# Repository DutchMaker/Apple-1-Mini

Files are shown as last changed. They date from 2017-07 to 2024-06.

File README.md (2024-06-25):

# Apple 1 Mini

*This build is currently in progress*

This project is a minified replica of the [**Apple 1**](https://en.wikipedia.org/wiki/Apple_I).  
It's built around a 6502 CPU, 6821 PIA (Peripheral Interface Adapter), RAM and ROM - just like the original Apple 1, but it uses an Arduino Nano to enable serial communication between the Apple 1 board and an external computer that acts as terminal.  
That means you can't hook up a keyboard and monitor directly to the board (yet!).  

The project is heavily inspired by the [*Briel Computers Apple 1 Replica*](http://www.brielcomputers.com/wordpress/?cat=17) and [*The Ben Heck Show*](https://github.com/thebenheckshow/158-tbhs-apple-1-replica)!

**What I have done:**
- [Redesigned the circuit](https://github.com/DutchMaker/Apple-1-Mini/blob/master/design/DesignSpark/revision1/schematic%20-%20Schematic.pdf) so I would fully understand every aspect of it.
- Designed a PCB that can be easily produced and included in a **modular DIY kit** for anyone that wants to build this at home.
- Programmed the ROM so it only contains BASIC, Krusader (assembler) and the Woz Monitor (memory monitor).
- Written firmware for the Arduino to enable serial communication in a way that gives the real *Apple 1 feeling*.
- Written a simple utility to upload data to the computer. This proved to be difficult with existing tools as there need to be specific delays in sending the data.

**What I have planned:**
- Design an expansion board that allows you to connect a keyboard an monitor directly to the board and run the Apple 1 standalone. The main PCB has an expansion header that allows an expansion board to be put on top of it (like a breakout board).
- Design a modular casing with laser cut parts. The casing will house the main board, but additional layers can be put on top of it to increase its size and allow for expansion boards to be added later on.
- Release several varations of a DIY kit for this project (PCB only, PCB + passives, PCB + passives + casing, complete kit, etc.) so others can easily build the computer at home.

**UPDATE (June 2024): Printer & SD storage support**  
[Simon Boak](https://github.com/simonboak/SB-A1) has added printer and SD storage support to the firmware.  
Read all about it in his detailed blog post: https://unimplementedtrap.com/apple-1-with-printer-sd-storage  
Thank you for this excellent contribution, Simon!

**Pictures of revision 1:**  

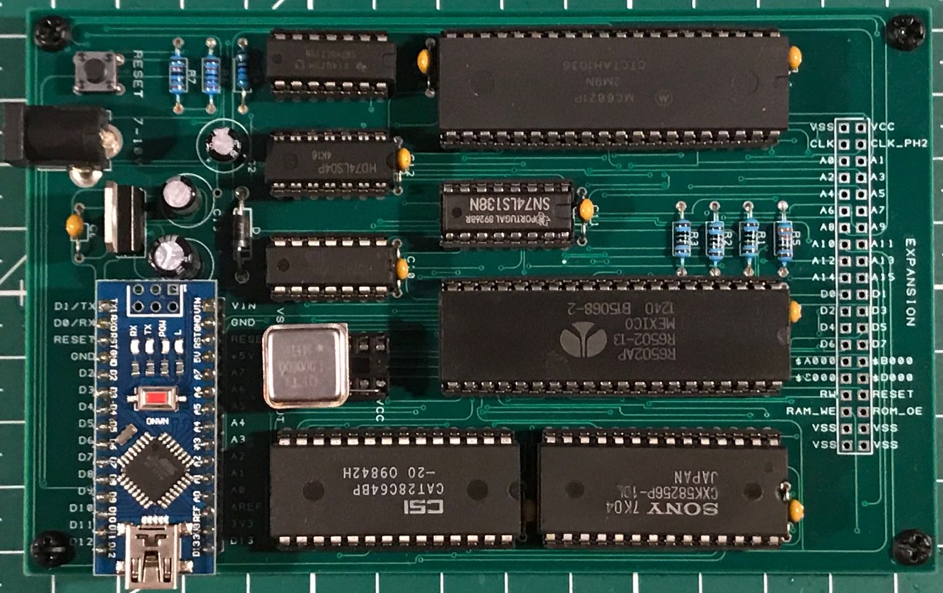
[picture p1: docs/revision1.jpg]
  
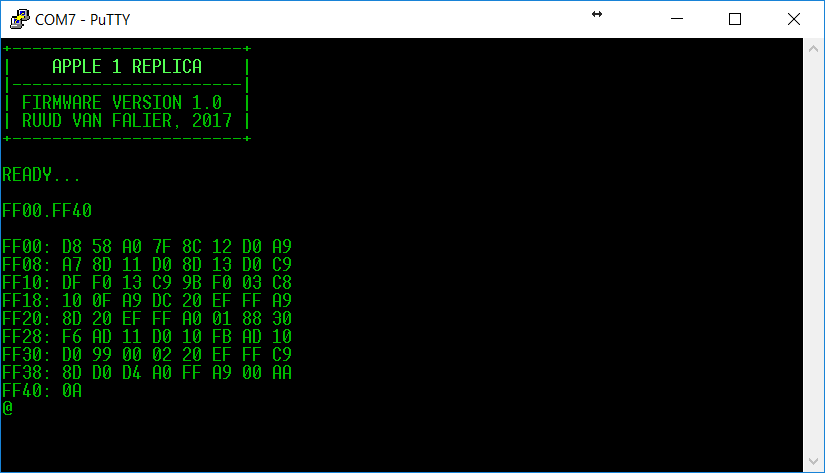
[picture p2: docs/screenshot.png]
  
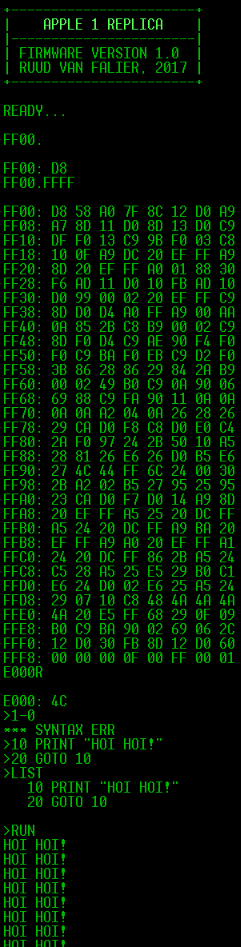
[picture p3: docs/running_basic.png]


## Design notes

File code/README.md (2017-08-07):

# Code folders

## Firmware
Contains Arduino code for the Apple 1 Mini firmware.

## Memory
Memory dump for the ROM.

## Programs
Program code for Apple 1 programs.

## Utilities
Utilities you may want to use with your Apple 1 Mini.

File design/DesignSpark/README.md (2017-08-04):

# Schematic & PCB design

You need to download [DesignSpark PCB 8](https://www.rs-online.com/designspark/pcb-software) to view & edit the schematic and PCB. 
Add the components folder to your component library first!  
 
The schematic is also [available as PDF](https://github.com/DutchMaker/Apple-1-Replica/blob/master/design/DesignSpark/revision1/schematic%20-%20Schematic.pdf).

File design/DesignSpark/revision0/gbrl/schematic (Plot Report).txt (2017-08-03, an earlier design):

Plot Report
-----------

Report Written:     Thursday, July 20, 2017
Design Path:        E:\Personal\Projects\Apple-1-Replica\design\DesignSpark\schematic.pcb
Design Title:       
Created:            20-7-2017 11:04:34
Last Saved:         20-7-2017 21:08:31
Editing Time:       603 min
Units:              mm (precision 1)

Device Settings
===============

Gerber Settings
===============

    Leading zero suppression.
    G01 assumed throughout.
    Line termination <*> <CR> <LF>.
    3.5 format absolute inches.

    Format commands defined in Gerber file.
    Aperture table defined in Gerber file.
    Hardware arcs allowed.

Drill Settings
==============

    Excellon Format 1    Format 3.5 absolute in inches.
    No zero suppression.

Plots Output
============

    Plot Job: "E:\Personal\Projects\Apple-1-Replica\design\DesignSpark\schematic.mop"

Gerber Output
=============

E:\Personal\Projects\Apple-1-Replica\design\DesignSpark\schematic - Top Silkscreen.gbr

    Layers:
    ------------------
    Top Silkscreen
    Board Outlines

    D-Code Shape  (thou)
    -----------------------
    D10    Round 19.69
    D11    Round 7.87
    D12    Round 5.00
    D13    Round 6.00
    D14    Round 3.00
    D15    Round 10.00
    D16    Round 16.00
    D17    Round 12.00

Gerber Output
=============

E:\Personal\Projects\Apple-1-Replica\design\DesignSpark\schematic - Top Copper.gbr

    Layers:
    --------------
    Top Copper

    D-Code Shape  (thou)
    ------------------------------------------
    D12    Round 5.00
    D15    Round 10.00
    D18    Round 196.85
    D19    Oval 60.00 X 110.00  Rotation 90
    D70    Round 60.00
    D71    Square 60.00
    D20    Oval 60.00 X 110.00
    D21    Round 70.00
    D22    Round 86.00
    D23    Round 56.00
    D24    Round 20.00
    D25    Round 32.00

Gerber Output
=============

E:\Personal\Projects\Apple-1-Replica\design\DesignSpark\schematic - Top Copper (Resist).gbr

    Layers:
    --------------
    Top Copper

    D-Code Shape  (thou)
    ------------------------------------------
    D26    Round 206.85
    D27    Oval 70.00 X 120.00  Rotation 90
    D28    Round 70.00
    D29    Square 70.00
    D72    Oval 70.00 X 120.00
    D73    Round 80.00
    D74    Round 96.00

Gerber Output
=============

E:\Personal\Projects\Apple-1-Replica\design\DesignSpark\schematic - Bottom Copper.gbr

    Layers:
    -----------------
    Bottom Copper

    D-Code Shape  (thou)
    ------------------------------------------
    D12    Round 5.00
    D15    Round 10.00
    D18    Round 196.85
    D19    Oval 60.00 X 110.00  Rotation 90
    D70    Round 60.00
    D71    Square 60.00
    D21    Round 70.00
    D22    Round 86.00
    D23    Round 56.00
    D24    Round 20.00
    D25    Round 32.00
    D75    Oval 60.00 X 110.00

Gerber Output
=============

E:\Personal\Projects\Apple-1-Replica\design\DesignSpark\schematic - Bottom Copper (Resist).gbr

    Layers:
    -----------------
    Bottom Copper

    D-Code Shape  (thou)
    ------------------------------------------
    D26    Round 206.85
    D27    Oval 70.00 X 120.00  Rotation 90
    D28    Round 70.00
    D29    Square 70.00
    D72    Oval 70.00 X 120.00
    D73    Round 80.00
    D74    Round 96.00

NC Drill Output
===============

E:\Personal\Projects\Apple-1-Replica\design\DesignSpark\schematic - Drill Data - [Through Hole].drl

    Output:
    ---------------------------
    Plated Round Drill Holes
    Plated Slots
    Plated Board Outlines

    Tool  Size         Count   ID
    ------------------------------------
    T001  000.01600 in 363
    T002  000.03200 in 272
    T003  000.03500 in 72
    T004  000.03937 in 4
    T005  000.04200 in 3
    T006  000.06200 in 2
    T007  000.11811 in 4
    ------------------------------------
    Total              720
    ------------------------------------

E:\Personal\Projects\Apple-1-Replica\design\DesignSpark\schematic - Drill Data - [Through Hole] (Unplated).drl

    Output:
    -----------------------------
    Unplated Round Drill Holes
    Unplated Slots
    Unplated Board Outlines

    Tool  Size         Count   ID
    ------------------------------------
    T001  000.02500 in 1
    ------------------------------------
    Total              1
    ------------------------------------

Gerber Output
=============

E:\Personal\Projects\Apple-1-Replica\design\DesignSpark\schematic - Drill Ident Drawing - [Through Hole].gbr

    Layers:
    ------------------
    [Through Hole]

Drill Ident Drawing
===================

    Drill Plated Size Shape ID
    -----------------------------------
    118   Y      100  Round A
    32    Y      100  Round B
    35    Y      100  Round C
    39    Y      100  Round D
    42    Y      100  Round E
    62    Y      100  Round F
    16    Y      100  Round G

    D-Code Shape  (thou)
    -----------------------
    D12    Round 5.00
    D76    Round 100.00

End Of Report.

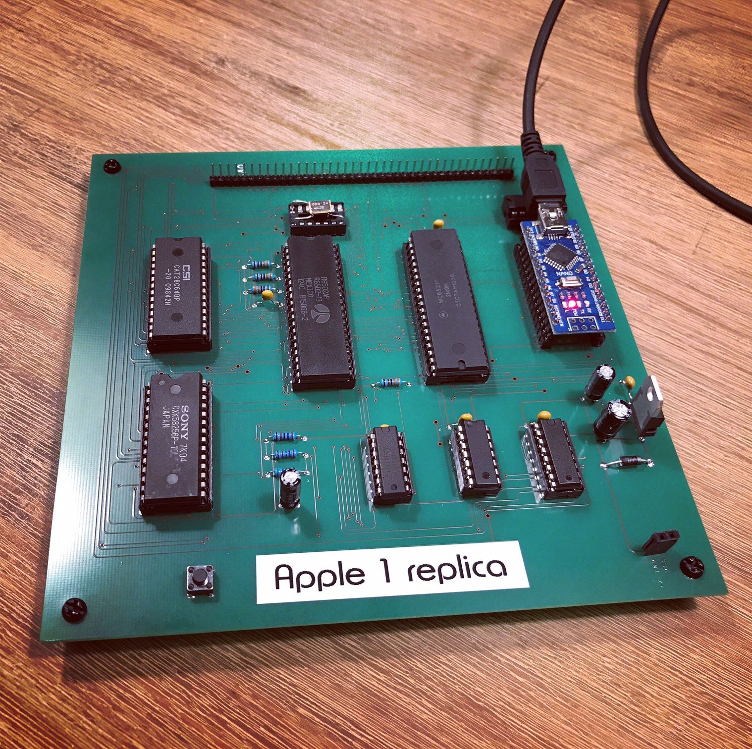
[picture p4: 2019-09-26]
docs/revision0.jpg

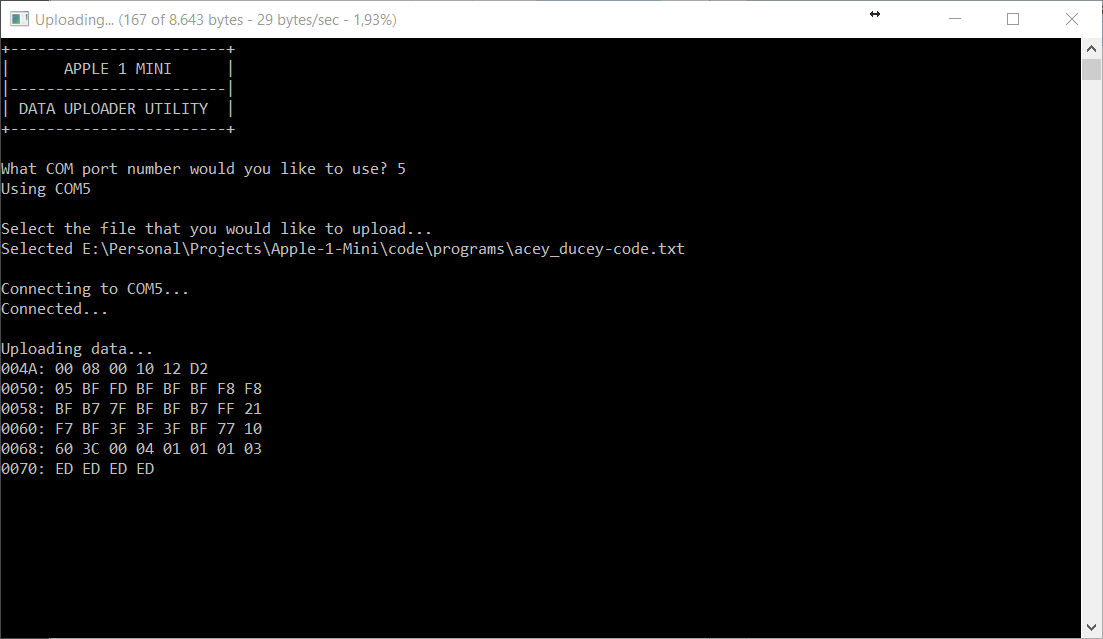
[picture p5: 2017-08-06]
docs/data-uploader.png

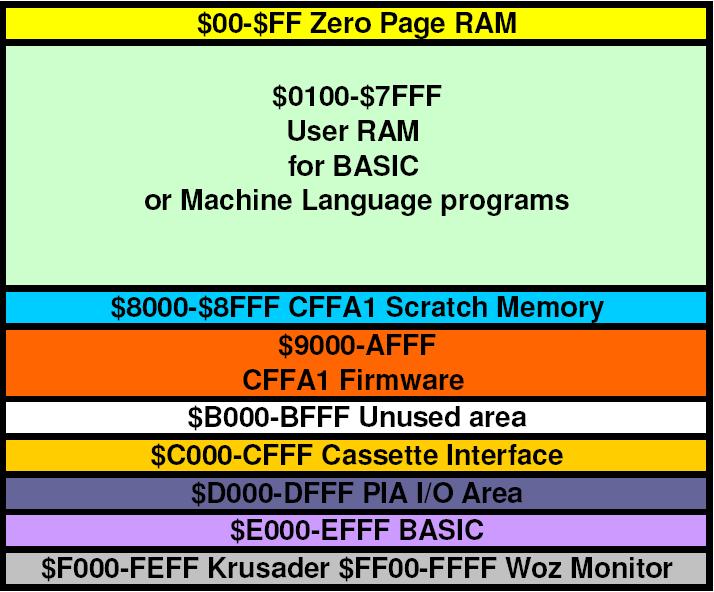
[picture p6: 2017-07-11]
code/memory/memory-map.jpg

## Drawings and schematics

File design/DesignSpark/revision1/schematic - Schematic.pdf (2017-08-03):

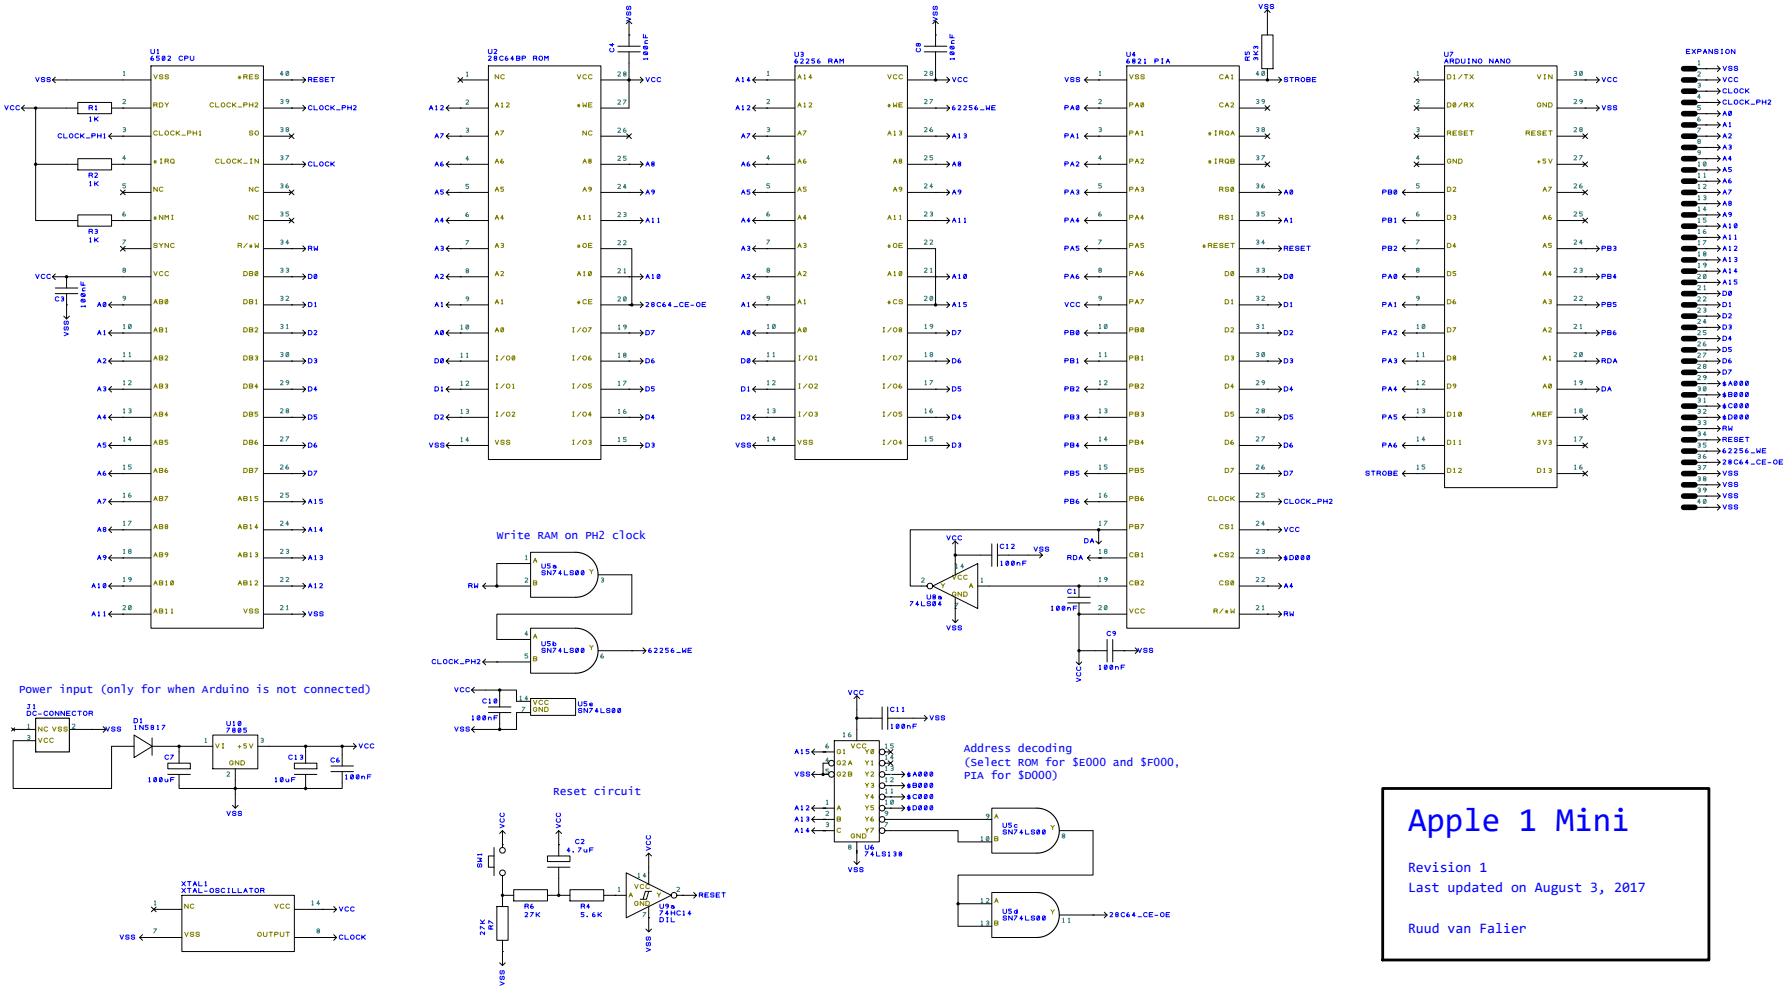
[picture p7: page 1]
Apple 1 Mini; Reset circuit

Write RAM on PH2 clock

Power input (only for when Arduino is not connected)

Address decoding
(Select ROM for $E000 and $F000,
PIA for $D000)

Revision 1
Last updated on August 3, 2017

Ruud van Falier

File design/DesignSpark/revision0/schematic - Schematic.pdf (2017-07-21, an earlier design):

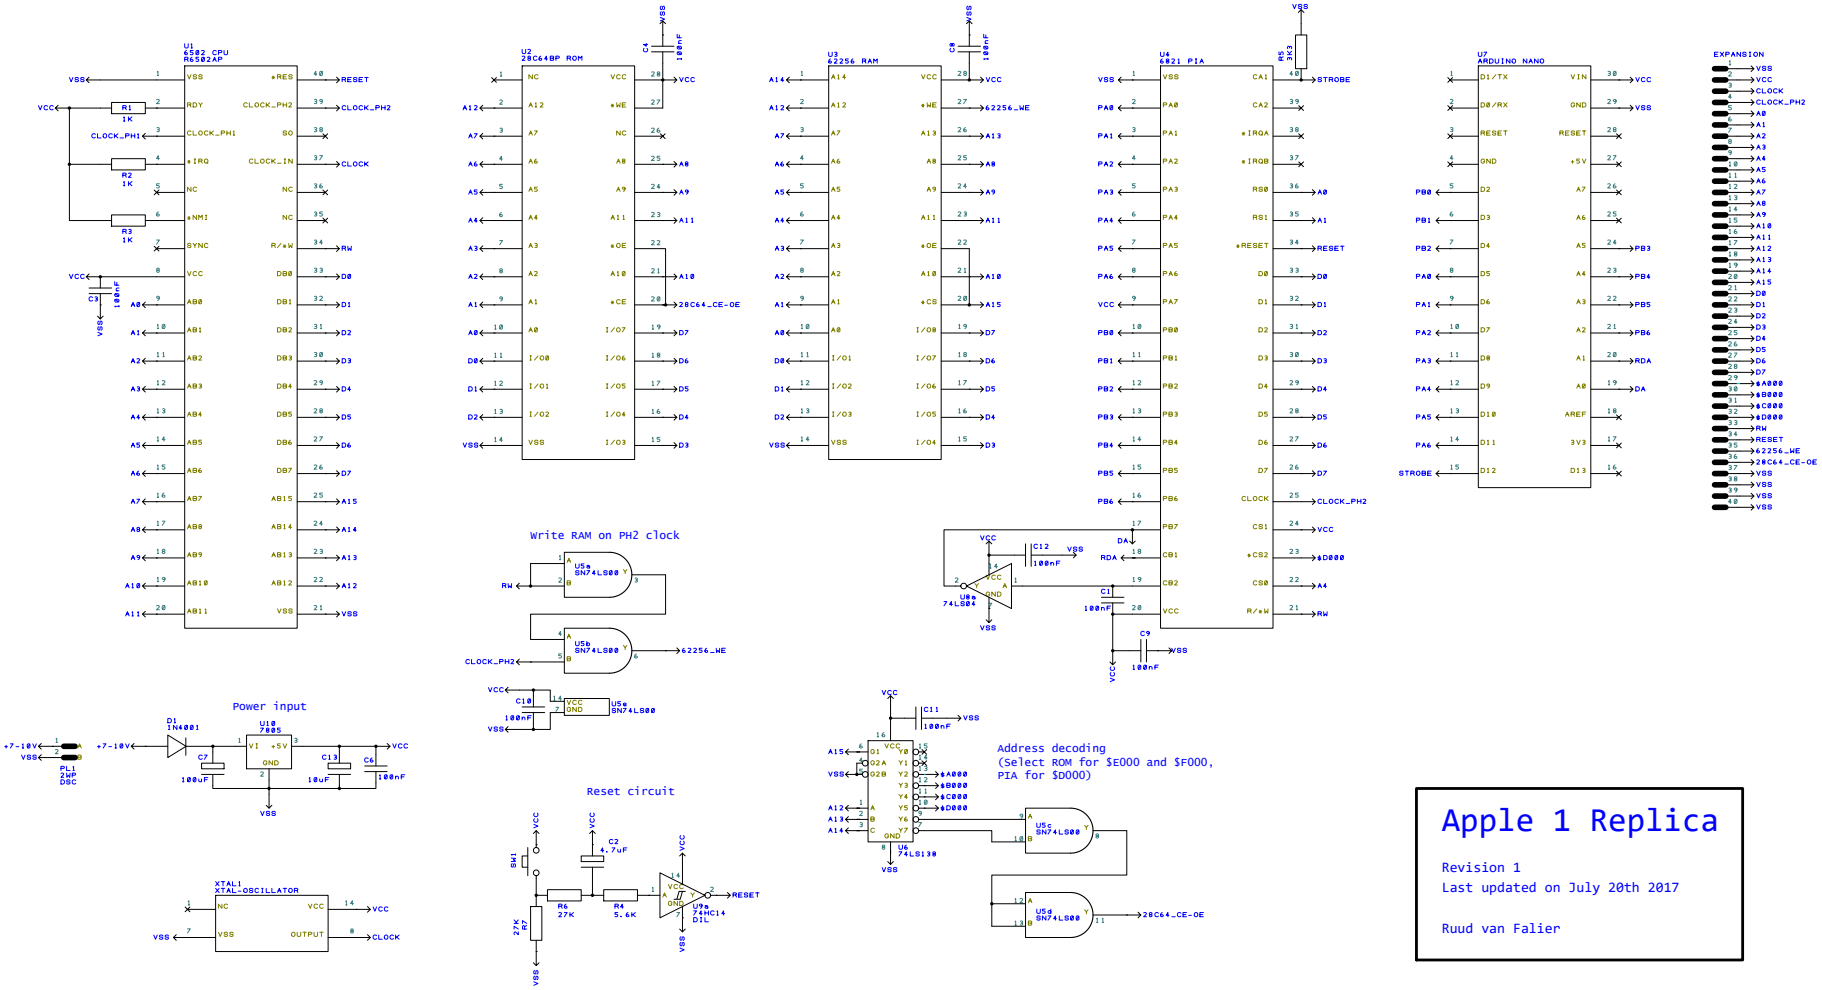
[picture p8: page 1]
Apple 1 Replica; Power input; Reset circuit

Write RAM on PH2 clock

Address decoding
(Select ROM for $E000 and $F000,
PIA for $D000)

Revision 1
Last updated on July 20th 2017

Ruud van Falier

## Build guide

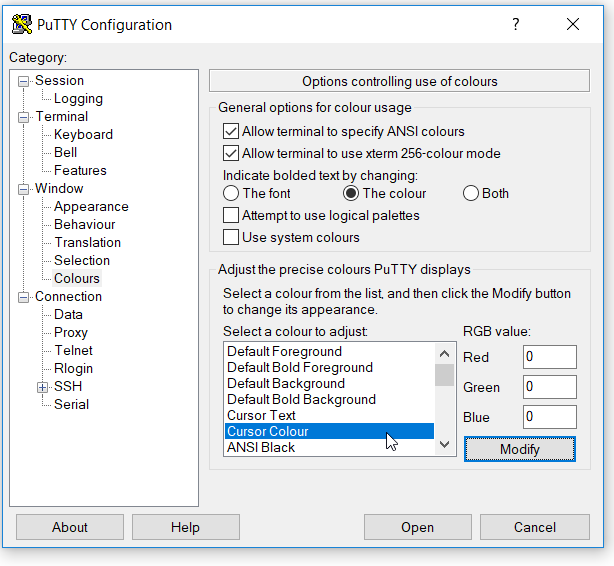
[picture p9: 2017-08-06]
docs/PuTTY-setup/PuTTY settings colours cursor.png

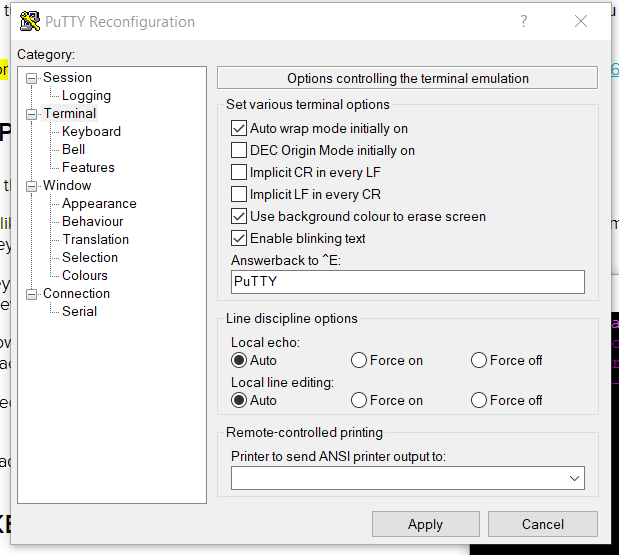
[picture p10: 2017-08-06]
docs/PuTTY-setup/PuTTY settings.png

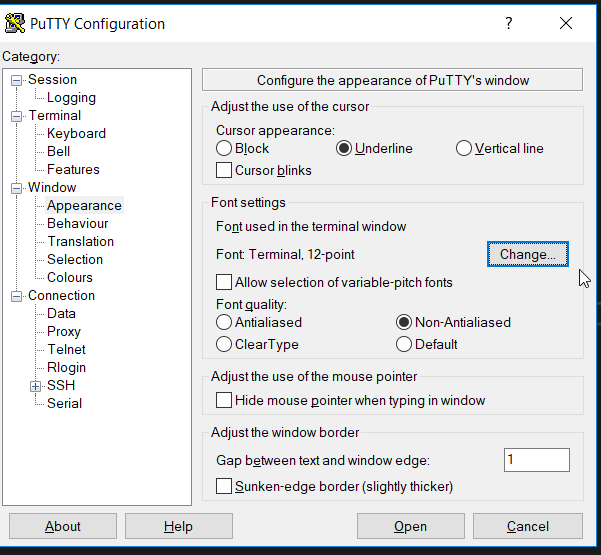
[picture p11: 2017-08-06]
docs/PuTTY-setup/PuTTY settings font.png

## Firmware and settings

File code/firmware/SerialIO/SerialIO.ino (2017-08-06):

// ---------------------------------------------------------------------------------- //
// Apple 1 Mini firmware for Arduino                                                  //
//                                                                                    //
// Version 1.0                                                                        //
// By Ruud van Falier                                                                 //
//                                                                                    //
// Enables serial communication between an Arduino and the Apple 1 PIA.               //
// Also implements a blinking cursor and green text using VT100 escape codes          //
// (VT100 codes only tested with PuTTY client!)                                       //
//                                                                                    //
// Heavily based on Propeller source code from Briel Computers' Apple 1 replica.      //
// ---------------------------------------------------------------------------------- //

// Port definitions (Arduino pins connected to the PIA)
#define PIN_DA  A0
#define PIN_RDA A1
#define PIN_PB0 2
#define PIN_PB1 3
#define PIN_PB2 4
#define PIN_PB3 A5
#define PIN_PB4 A4
#define PIN_PB5 A3
#define PIN_PB6 A2
#define PIN_PA0 5
#define PIN_PA1 6
#define PIN_PA2 7
#define PIN_PA3 8
#define PIN_PA4 9
#define PIN_PA5 10
#define PIN_PA6 11
#define PIN_STROBE 12

#define DELAY_VIDEO 1
#define DELAY_ASCII 1

// VT100 codes (used for cursor and text color implementation)
#define VT100_OFF           "\033[0m"     // Disable formatting
#define VT100_DEFAULT       "\033[32m"    // Color green
#define VT100_BLINK         "\033[5;32m"  // Blink color green
#define VT100_BOLD          "\033[1;32m"  // Bold color green
#define VT100_CLS           "\033[2J"     // Clear screen
#define VT100_RESET_CURSOR  "\033[H"      // Position cursor in top left corner
#define VT100_CURSOR_LEFT   "\033[1D"     // Move cursor one column to the left
#define VT100_ERASE_EOL     "\033[K"      // Erase from cursor until end of line
#define CURSOR_CHAR   "@"

// Global variables
uint8_t video_data = 0;
uint8_t video_data_pins[] = { PIN_PB0, PIN_PB1, PIN_PB2, PIN_PB3, PIN_PB4, PIN_PB5, PIN_PB6 };
uint8_t serial_data;

bool cursor_visible = false;

/*
 * Program initialization
 */
void setup() 
{
  // Setup video data pins (output from the PIA)
  pinMode(PIN_RDA, OUTPUT);
  pinMode(PIN_DA, INPUT);
  pinMode(PIN_PB0, INPUT);
  pinMode(PIN_PB1, INPUT);
  pinMode(PIN_PB2, INPUT);
  pinMode(PIN_PB3, INPUT);
  pinMode(PIN_PB4, INPUT);
  pinMode(PIN_PB5, INPUT);
  pinMode(PIN_PB6, INPUT);

  // Setup ASCII data pins (input for the PIA)
  pinMode(PIN_STROBE, OUTPUT);
  pinMode(PIN_PA0, OUTPUT);
  pinMode(PIN_PA1, OUTPUT);
  pinMode(PIN_PA2, OUTPUT);
  pinMode(PIN_PA3, OUTPUT);
  pinMode(PIN_PA4, OUTPUT);
  pinMode(PIN_PA5, OUTPUT);
  pinMode(PIN_PA6, OUTPUT);

  Serial.begin(9600);
 
  display_boot_message();
}

/*
 * Program loop
 */
void loop() 
{
  process_video_data();
  process_serial_data(); 
}

/*
 * Displays the Apple 1 Replica firmware boot message and enables the blinking cursor
 */
void display_boot_message()
{
  cursor_visible = false;

  Serial.print(VT100_CLS);
  Serial.print(VT100_RESET_CURSOR);
  Serial.print(VT100_OFF);
  Serial.print(VT100_DEFAULT);
  Serial.println("+------------------------+");
  Serial.print("|      ");
  Serial.print(VT100_OFF);
  Serial.print(VT100_BOLD);
  Serial.print("APPLE 1 MINI");
  Serial.print(VT100_OFF);
  Serial.print(VT100_DEFAULT);
  Serial.println("      |");
  Serial.print(VT100_OFF);
  Serial.print(VT100_DEFAULT);
  Serial.println("|------------------------|");
  Serial.println("| FIRMWARE VERSION 1.0   |");
  Serial.println("| RUUD VAN FALIER, 2017  |");
  Serial.println("+------------------------+");
  Serial.println();
  Serial.println("READY...");
  Serial.println();
  Serial.print(VT100_OFF);

  show_cursor();
}

/*
 * Retrieves video (character) data from the PIA and sends it to the user over the serial connection.
 */
void process_video_data()
{
  // Tell the PIA we are ready to receive data.
  digitalWrite(PIN_RDA, HIGH);
  delay(DELAY_VIDEO);

  while (digitalRead(PIN_DA))
  {
    // Data is available.
    video_data = 0;

    // Decode the data bits to a byte.
    for (int i = 0; i < 7; i++)
    { 
      if (digitalRead(video_data_pins[i]))
      {
        video_data |= (1 << i);
      }
    }

    // Send video data over serial connection.
    if (video_data == 13)
    {
      // Carrage return.
      hide_cursor();
      Serial.println();
    }
    else if (video_data > 31)
    {
      // Display-compatible character.
      hide_cursor();
      Serial.print(VT100_DEFAULT);
      Serial.print((char)video_data);
      Serial.print(VT100_OFF);
    }

    // Done receiving this byte.
    digitalWrite(PIN_RDA, LOW);
    delay(DELAY_VIDEO);

    // Tell the PIA we are ready to receive more data.
    digitalWrite(PIN_RDA, HIGH);
    delay(DELAY_VIDEO);
  }

  show_cursor();
}

/*
 * Processes data received from the serial connection.
 * Puts the received data on to the PIA where the CPU will read it from.
 */
void process_serial_data()
{
  // Wait for serial data coming in.
  while (Serial.available() > 0)
  {
    serial_data = Serial.read();

    if (serial_data == 203) 
    {
      // Translate uppercase ESC to normal ESC.
      serial_data = 27;
    }

    if (serial_data >= 97 && serial_data <= 122)
    {
      // Translate lowercase characters to uppercase as the Apple 1 only supports uppercase.
      serial_data -= 32;
    }

    if (serial_data < 96)   
    {
      // Encode any Apple 1 compatible character to data bits.
      digitalWrite(PIN_PA6, bitRead(serial_data, 6));
      digitalWrite(PIN_PA5, bitRead(serial_data, 5));
      digitalWrite(PIN_PA4, bitRead(serial_data, 4));
      digitalWrite(PIN_PA3, bitRead(serial_data, 3));
      digitalWrite(PIN_PA2, bitRead(serial_data, 2));
      digitalWrite(PIN_PA1, bitRead(serial_data, 1));
      digitalWrite(PIN_PA0, bitRead(serial_data, 0));

      // Pulse the STROBE bit so the PIA will process the input.
      digitalWrite(PIN_STROBE, HIGH);
      delay(DELAY_ASCII);
      digitalWrite(PIN_STROBE, LOW);
    }

    process_video_data();
  }
}

/*
 * Remove the cursor character from the screen by sending a backspace.
 */
void hide_cursor()
{
  if (cursor_visible)
  {
    Serial.print(VT100_CURSOR_LEFT);
    Serial.print(VT100_ERASE_EOL);
    cursor_visible = false;
  }
}

/*
 * Display blinking cursor character.
 */
void show_cursor()
{
  if (!cursor_visible)
  {
    Serial.print(VT100_BLINK);
    Serial.print(CURSOR_CHAR);
    Serial.print(VT100_OFF);
    cursor_visible = true;
  }
}

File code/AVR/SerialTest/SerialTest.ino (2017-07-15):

#define DA  A0
#define RDA A1
#define PB0 2
#define PB1 3
#define PB2 4
#define PB3 A5
#define PB4 A4
#define PB5 A3
#define PB6 A2
#define PA0 5
#define PA1 6
#define PA2 7
#define PA3 8
#define PA4 9
#define PA5 10
#define PA6 11
#define STROBE 12

uint8_t video_data = 0;
uint8_t video_data_pins[] = { PB0, PB1, PB2, PB3, PB4, PB5, PB6 };
uint8_t serial_data;

void setup() 
{
  // Video data pins
  pinMode(RDA, OUTPUT);
  pinMode(DA, INPUT);
  pinMode(PB0, INPUT);
  pinMode(PB1, INPUT);
  pinMode(PB2, INPUT);
  pinMode(PB3, INPUT);
  pinMode(PB4, INPUT);
  pinMode(PB5, INPUT);
  pinMode(PB6, INPUT);

  // ASCII data pins
  pinMode(STROBE, OUTPUT);
  pinMode(PA0, OUTPUT);
  pinMode(PA1, OUTPUT);
  pinMode(PA2, OUTPUT);
  pinMode(PA3, OUTPUT);
  pinMode(PA4, OUTPUT);
  pinMode(PA5, OUTPUT);
  pinMode(PA6, OUTPUT);

  Serial.begin(9600);
  Serial.println("Arduino ready...");
}

void loop() 
{
  process_video_data();
  process_serial_data();  
}

void process_video_data()
{
  digitalWrite(RDA, HIGH);
  delayMicroseconds(20);

  if (digitalRead(DA))
  {
    video_data = 0;

    for (int i = 0; i < 7; i++)
    { 
      if (digitalRead(video_data_pins[i]))
      {
        video_data |= (1 << i);
      }
    }

    if (video_data == 13)
    {
      Serial.println();
    }
    else if (video_data > 31)
    {
      Serial.print((char)video_data);
    }

    digitalWrite(RDA, LOW);
    delayMicroseconds(20);
  }
}

void process_serial_data()
{
  if (Serial.available() > 0) 
  {
    serial_data = Serial.read();

    if (serial_data == 203) // Uppercase ESC
    {
      serial_data = 27;
    }

    if (serial_data >= 97 && serial_data <= 122)  // lower case a-z
    {
      serial_data -= 32;
    }

    if (serial_data < 96)   // Is the character Apple 1 compatible?
    {      
      digitalWrite(PA6, bitRead(serial_data, 6));
      digitalWrite(PA5, bitRead(serial_data, 5));
      digitalWrite(PA4, bitRead(serial_data, 4));
      digitalWrite(PA3, bitRead(serial_data, 3));
      digitalWrite(PA2, bitRead(serial_data, 2));
      digitalWrite(PA1, bitRead(serial_data, 1));
      digitalWrite(PA0, bitRead(serial_data, 0));

      digitalWrite(STROBE, HIGH);
      delayMicroseconds(20);
      digitalWrite(STROBE, LOW);
    }

    /*
    if (serial_data == 13)
    {
      Serial.println();
    }
    else
    {
      Serial.print((char)serial_data);
    }
    */
  }
}

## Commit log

2017-07-11 Added ROM image
    [schematic.sch]
2017-07-13 Schematic for PIA updated
    [schematic.sch]
2017-07-14 Added code for apple 1 programs and started AVR code for IO
    [schematic.sch]
2017-07-15 Updated schematic
    [schematic.sch]
2017-07-20 Removed crystal oscillator from schematic
    [schematic.sch]
2017-07-20 Schematic work in progress
    [schematic.sch]
2017-07-21 Rough draft of a PCB (autorouted) that has been sent to the manufacturer for a first test board
    [schematic.sch]
2017-08-01 Prepping for first production revision
    [schematic_r2.sch]
2017-08-02 Designing new PCB
    [schematic.sch, schematic_r2.sch]
2017-08-03 Added DC power connector
    [schematic.sch]
2017-08-03 Revision 1 submitted for PCB production (single board)
    [schematic - Board Outline.gbr, schematic - Bottom Copper (Paste).gbr, schematic - Bottom Copper (Resist).gbr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]
2017-08-04 More readme and renaming the repository
    [schematic.sch]
2017-08-04 More readme...
    [schematic.sch]
2019-09-26 Updated picture of board
